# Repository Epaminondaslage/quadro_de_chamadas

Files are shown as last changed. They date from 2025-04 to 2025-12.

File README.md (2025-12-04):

<td style="width: 10%;">
    
</td>

## **CENTRO FEDERAL DE EDUCAÇÃO TECNOLÓGICA DE MINAS GERAIS**  
## **Departamento de Engenharia Elétrica - CEFET-MG**  
## **Coordenação do Curso de Eletrotécnica**  

###  Disciplina: **PLIEP - Prática de Laboratório de Instalações Eletricas Prediais**
## Guia de Aula – Quadro Sinalizador de Chamadas de Enfermagem

##  O que é um sistema de chamada de enfermagem?

É um sistema que permite aos pacientes sinalizar a necessidade de assistência por parte da equipe de enfermagem, geralmente em ambientes hospitalares ou casas de repouso. Ele utiliza sinais sonoros e luminosos para alertar os profissionais de saúde sobre a necessidade de atendimento. 

Esse sinal é enviado para uma **central de monitoramento** 🛋️, localizada em local visível a todos os profissionais. Veja na imagem que segue um modelo comercial empregado em hospitais e clinicas.

<p align="center">
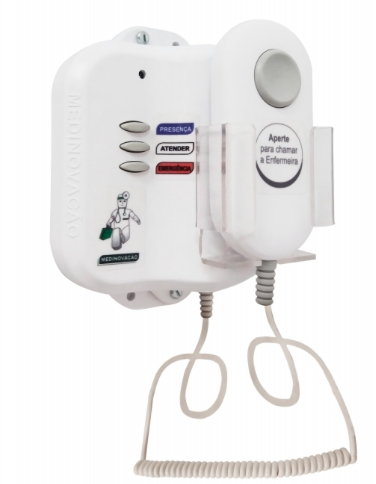
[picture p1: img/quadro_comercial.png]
Quadro de chamadas comercial
  
</p>

Além disso, o sistema permite que os profissionais de saúde **registrem a sua presença no leito** do paciente que gerou a chamada, sinalizando ao restante da equipe que o **atendimento está em andamento**.

## 🔧 Como funciona um sistema de chamada de enfermagem?

O paciente aciona a estação de chamada. 

O sinaleiro de porta acende, sinalizando a chamada externamente. 
A central do posto de enfermagem é acionada, indicando o número do leito ou do banheiro que solicitou ajuda. 
O profissional de enfermagem aciona o botão de presença para indicar que está atendendo à chamada. 
Após o atendimento, o profissional aciona novamente o botão de presença para desligar a chamada. 

<p align="center">
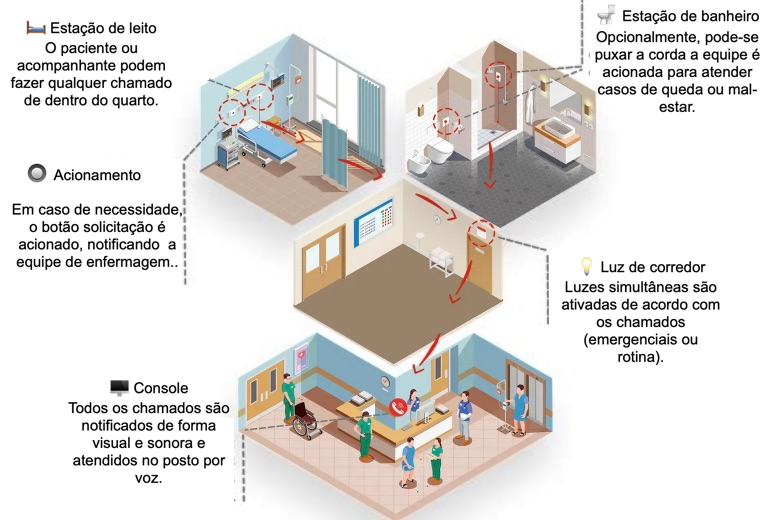
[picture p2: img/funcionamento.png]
Qoperacao
  
</p>

Benefícios:

    Melhora a comunicação entre pacientes e equipe de enfermagem. 

Agiliza o atendimento, reduzindo o tempo de espera dos pacientes. 
Aumenta a segurança dos pacientes, permitindo que eles solicitem ajuda rapidamente em caso de necessidade. 
Permite que a equipe de enfermagem monitore a atividade e a demanda de atendimento em tempo real. 

Um **sistema de chamada de enfermagem** é composto por diferentes dispositivos, adaptados às necessidades do ambiente hospitalar:

### 🛉 Estação de Chamada de Enfermagem

Dispositivos fixados na parede ou painéis de gases medicinais, acessíveis por um **cordão com pera sensível ao toque 🌟**.

### 🔦 Sinaleiro de Porta

Indicadores visuais fixados **acima das portas** para alertar sobre chamadas em andamento, utilizando diferentes **cores 🟥**.

### 🛋️ Central do Posto de Enfermagem

Dispositivo centralizado que **monitora e sinaliza** todas as chamadas ativas.

---

## Guia de Aula Prática: Montagem do Quadro de Chamadas

Com o objetivo de **capacitar os alunos do 2º ano do Curso de Eletrotécnica**, esta aula prática propõe a montagem de um **Quadro de Chamadas de Enfermagem**, que será instalado na parede externa do **Box 4** do Laboratório de Instalações Prediais.

Durante a atividade, os alunos aplicarão conceitos de eletrônica, comandos elétricos e automação, utilizando botões tipo pera, arandelas de sinalização e um sistema de controle baseado em microcontrolador **ESP32** com interface web.

➡️ Para detalhes completos do procedimento e materiais necessários, acesse o [Guia de Aula Prática de Montagem](https://github.com/Epaminondaslage/quadro_de_chamadas/blob/main/Guia_de_Aula_Pr%C3%A1tica.md).

---
## Retrofit do Quadro de Chamadas de Enfermagem

### O que é Retrofit?

**Retrofit** é o processo de **modernização e aprimoramento de sistemas, equipamentos ou estruturas já existentes**, visando **aumentar sua eficiência, funcionalidade e segurança**, ao mesmo tempo em que os adapta às **novas tecnologias**.  Em vez de substituir totalmente o que já foi construído, o retrofit promove uma **renovação inteligente**, aproveitando a infraestrutura física disponível e incorporando melhorias técnicas capazes de atender às exigências contemporâneas de desempenho e inovação.

➡️ Para detalhes completos do procedimento de retrofit veja : [Retrofit do Quadro de Chamadas de Enfermagem](https://github.com/Epaminondaslage/quadro_de_chamadas/blob/main/%F0%9F%94%A7%20Retrofit-do-Quadro-de-Chamadas.md).

---
## Projeto de um Quadro de Chamadas de Enfermagem Didático

O **Quadro de Chamadas** foi desenvolvido por professores do **CEFET-MG** com fins didáticos, com o objetivo de proporcionar aos alunos uma experiência prática em sistemas de automação e monitoramento. Utilizando o microcontrolador **ESP32**, o projeto simula um sistema real de chamadas de enfermagem, integrando entradas digitais (botões tipo pera) e saídas visuais (arandelas vermelhas) acionadas por relés. Além disso, inclui uma interface web para acompanhamento em tempo real das solicitações, reforçando conceitos de eletrônica, redes de comunicação e programação embarcada.

➡️ Para mais detalhes, consulte: [Projeto Quadro de Chamadas ESP32](https://github.com/Epaminondaslage/quadro_de_chamadas/blob/main/Projeto_Quadro_de_Chamadas_ESP32.md)

---

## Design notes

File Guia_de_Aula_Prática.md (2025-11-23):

<td style="width: 10%;">
    
</td>

## **CENTRO FEDERAL DE EDUCAÇÃO TECNOLÓGICA DE MINAS GERAIS**  
## **Departamento de Engenharia Elétrica - CEFET-MG**  
## **Coordenação do Curso de Eletrotécnica**  

## Disciplina: **PLIP - Prática de Laboratório de Instalações Prediais**
## Guia de Aula Prática: Montagem do Quadro de Chamadas de Enfermagem

## 🎓 Objetivo da Aula

Capacitar os alunos do **2º ano do Curso de Eletrotécnica** na montagem de um **Quadro de Chamadas de Enfermagem**, a ser instalado na parede externa do **Box 4** do Laboratório de Instalações Prediais.

## 📚 Descrição da Atividade

Cada box terá:
- Um **interruptor tipo pera** para acionar o chamado.

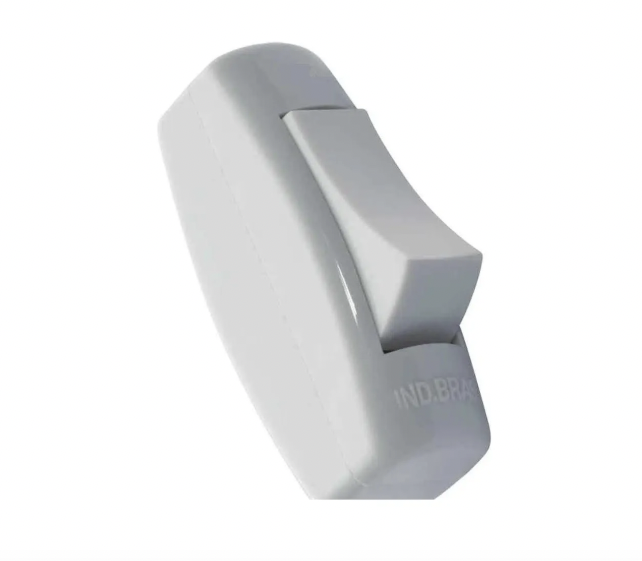
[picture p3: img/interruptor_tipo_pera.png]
interruptor_pera


- Uma **arandela vermelha** para sinalizar a solicitação de presença de um profissional de enfermagem.

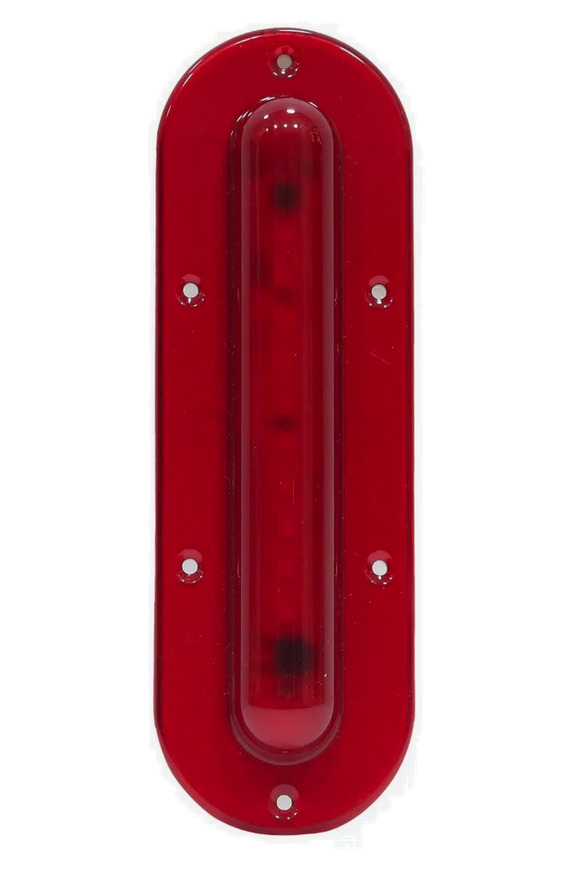
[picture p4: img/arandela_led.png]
arandela


O quadro central controlará as chamadas via **ESP32**, com registro e monitoramento através de uma **interface web**.

## 🛠️ Materiais Necessários

| Quantidade | Componente | Descrição |
|---|---|---|
| 1 | Quadro de Camada de Enfermagem | Microcontrolador e dispositivos eletronicos internos |
| 4 | Interruptor tipo pera | Acionadores de chamada |
| 4 | Arandelas vermelhas (127V)  | Indicadores de chamada |
| 1 | Fonte 127V  | Fonte de alimentação para o Quadro de chamadas |
| Cabos | Fios para conexões | Ligação dos dispositivos |

## 📊 Esquema de Conexão

- **Interruptores tipo pera** conectados às **entradas digitais** do Quadro onde está o ESP32.
- **Arandelas** conectadas a saídas dos **relés**, acionados pelas **saídas digitais** do ESP32.
- **Quadro de Chamadas de Enfermagem** alimentado em rede de 127V

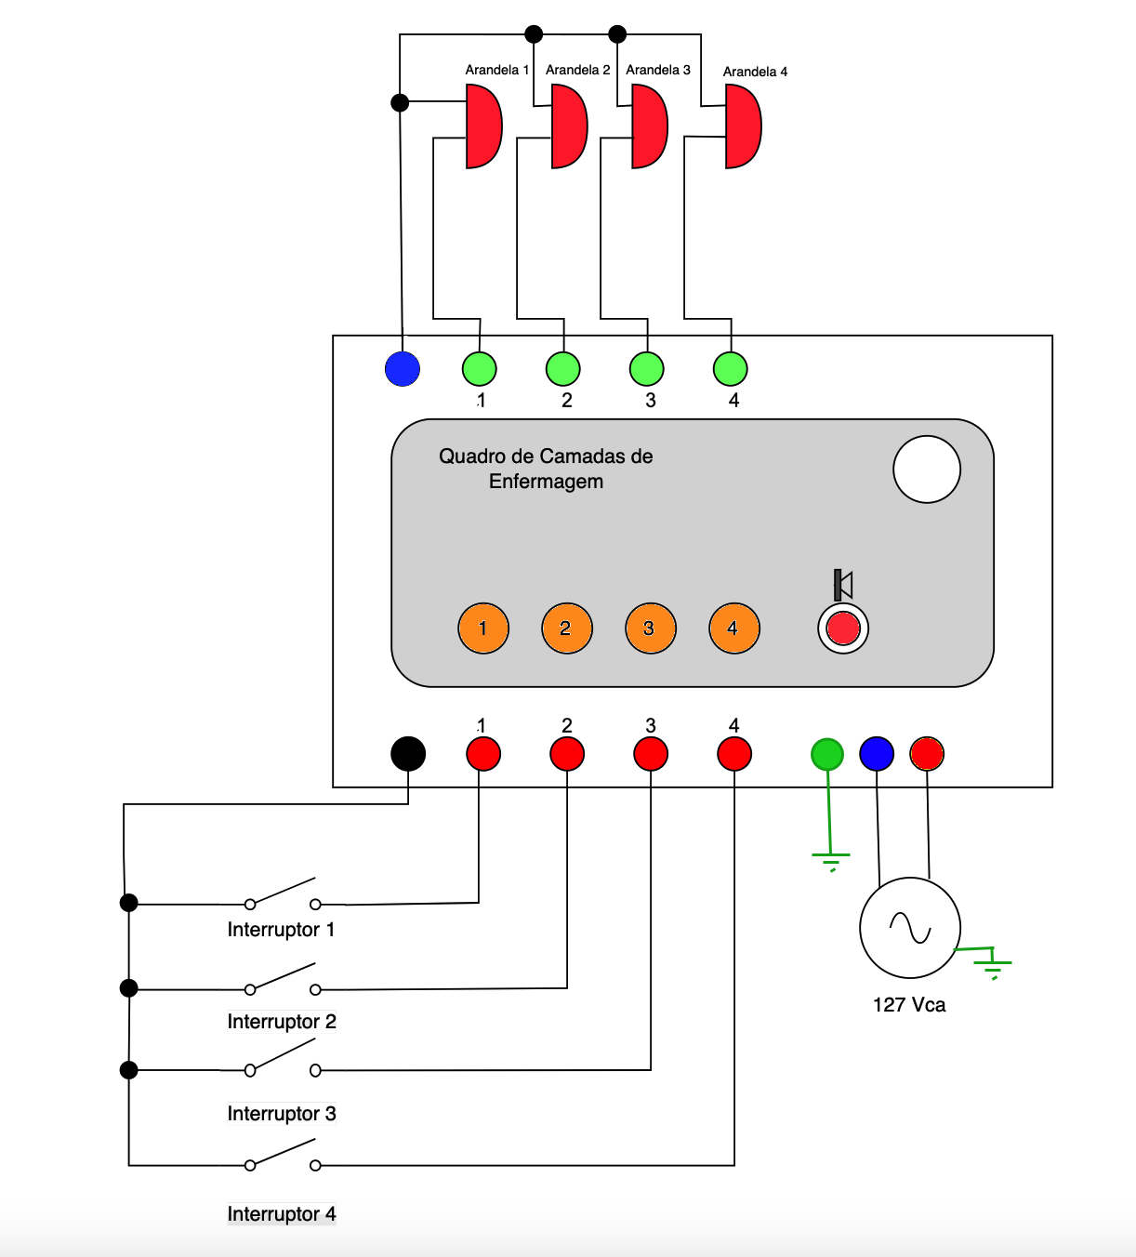
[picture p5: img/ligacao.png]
  

## 🔧 Procedimento de Montagem

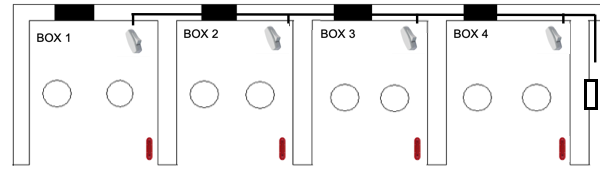
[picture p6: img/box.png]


## 📊 Atividades Propostas
- Realizar a montagem elétrica e mecânica dos equipamentos.
  
### 1. Ligação dos Interruptores
- Fixar o interruptor tipo pera em local acessível dentro de cada Box Didático
- Conectar uma extremidade do UTP e a outra a uma entrada no painel do ESP32 através do cabo UTP já instalado.

### 2. Ligação das Arandelas
- Instalar a arandela vermelha acima da porta dos Boxes 1 a 4.
- Conectar uma extremidade do cabo à arandela e a outra a uma entrada no painel do ESP32 através do cabo 1mm2 já instalado.

### 3. Instalação do Quadro de Chamadas
- Montar todo o circuito na base (painel) conectando os condutores conforme esquema que segue.

### 4. Testes Finais
- Acionar cada interruptor e verificar se a respectiva arandela acende.
- Acessar o wifi do Laboratório e monitorar o funcionamento do sistema pelo navegador de seu celular.Testar os comandos da interface web para monitorar os estados.

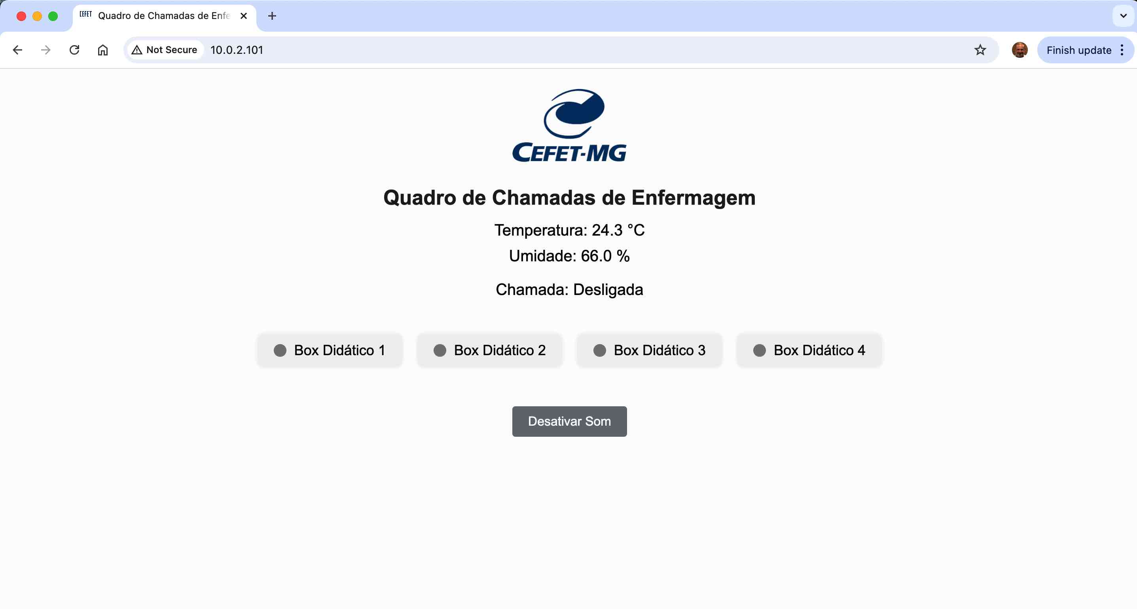
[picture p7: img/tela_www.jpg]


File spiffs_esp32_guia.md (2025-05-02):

# Guia: Usando `SPIFFS.h` no ESP32 

# 📦 O que é `SPIFFS.h`?

A biblioteca `SPIFFS.h` permite utilizar a memória **flash interna do ESP32** como um **sistema de arquivos**, possibilitando **armazenar e servir arquivos como HTML, CSS, JavaScript e imagens diretamente da placa**.

---

### ✅ Significado

**SPIFFS** = *SPI Flash File System*  
Sistema de arquivos leve, ideal para microcontroladores com memória flash limitada.

---

## ✅ Para que serve?

Com `SPIFFS`, é possível:

- Criar páginas web embarcadas (HTML/CSS/JS)
- Salvar imagens, logos ou ícones
- Armazenar configurações e logs
- Evitar hardcoding de textos HTML no `.ino`

---

## ✅ Exemplo de uso no código

```cpp
#include "SPIFFS.h"

void setup() {
  SPIFFS.begin(true); // Monta o sistema de arquivos
  server.serveStatic("/", SPIFFS, "/").setDefaultFile("index.html");
}
```

---

# 📦 Instalar Python 3, mkspiffs e enviar SPIFFS para ESP32 com MSYS2 (Arduino IDE 2.x)

Guia para instalar **Python 3**, `esptool.py`, `mkspiffs` e configurar o **MSYS2 MinGW 64-bit** para trabalhar com o ESP32.

---

## ✅ Etapa 1: Instalar Python 3 e pip

### ✅ 1. Baixar Python 3

[Baixe aqui](https://www.python.org/downloads/)

Marque **"Add Python 3.x to PATH"** na instalação.

### ✅ 2. Verificar instalação

```bash
python --version
pip --version
```

### ✅ 3. Instalar `esptool.py`

```bash
pip install esptool
esptool.py --help
```

---

## ✅ Etapa 2: Instalar o MSYS2

### ✅ 1. Baixar MSYS2

[Baixar aqui](https://www.msys2.org)

Instale em `C:\msys64`.

### ✅ 2. Abrir terminal correto

```
MSYS2 MinGW 64-bit
```

### ✅ 3. Atualizar sistema

```bash
pacman -Syu
```

### ✅ 4. Instalar ferramentas de compilação

```bash
pacman -S mingw-w64-x86_64-toolchain python-pip
```

---

## ✅ Etapa 3: Baixar o mkspiffs

[Download oficial do mkspiffs](https://github.com/earlephilhower/mkspiffs/releases)

Extraia para:

```
C:\esp32tools\mkspiffs.exe
```

---

## ✅ Etapa 4: Preparar o projeto

Estrutura recomendada:

```
meu_projeto/
├── meu_projeto.ino
└── data/
    ├── index.html
    ├── style.css
    └── script.js
```

---

## ✅ Etapa 5: Gerar a imagem SPIFFS

No terminal MSYS2 MinGW 64-bit:

```bash
cd /c/Users/SeuUsuario/Documents/Arduino/meu_projeto
/c/esp32tools/mkspiffs.exe -c data -b 4096 -p 256 -s 0x150000 spiffs.bin
```

---

## ✅ Etapa 6: Enviar a imagem para o ESP32

Identifique a porta COM do seu ESP32 e execute:

```bash
esptool.py --chip esp32 --port COM5 --baud 460800 write_flash 0x290000 spiffs.bin
```

---

## ✅ Endereço da partição SPIFFS

| Esquema de Particionamento | Endereço |
|---|---|
| Default 4MB with spiffs (1.2MB app) | 0x290000 |
| No OTA (2MB APP/2MB SPIFFS) | 0x290000 |

Verifique em:

> Arduino IDE > Ferramentas > Partition Scheme

---

## ✅ Etapa 7: Servir os arquivos SPIFFS

```cpp
#include "SPIFFS.h"

void setup() {
  SPIFFS.begin(true);
  server.serveStatic("/", SPIFFS, "/").setDefaultFile("index.html");
}
```

---

## ✅ Etapa 8: Testar no navegador

Acesse o IP do ESP32 no navegador para testar.

---

## ✅ Ambiente pronto!

Sistema configurado para enviar SPIFFS ao ESP32 usando Python 3, mkspiffs e MSYS2 na Arduino IDE 2.x.

---

# 💾 Arquivo BAT para Compilar e Enviar para o ESP32

## ✅ Objetivo do arquivo `.bat`

Automatizar:

1. Geração da imagem SPIFFS (`spiffs.bin`)
2. Upload da imagem SPIFFS para o ESP32

## ✅ Comandos usados:

### 1. Geração do spiffs.bin

```bash
mkspiffs.exe -c quadro_de_chamadas\quadro_de_chamadas\data -b 4096 -p 256 -s 0x150000 spiffs.bin
```

Parâmetros:
- `-c`: caminho dos arquivos
- `-b 4096`: tamanho do bloco
- `-p 256`: tamanho da página
- `-s 0x150000`: tamanho reservado para SPIFFS

### 2. Upload para ESP32

```bash
python -m esptool --chip esp32 --port COM8 --baud 460800 write_flash 0x290000 spiffs.bin
```

Parâmetros:
- `--chip esp32`: define o chip
- `--port COM8`: porta serial
- `--baud 460800`: velocidade de gravação
- `write_flash 0x290000`: endereço de gravação

---

## ✅ Resumo Simplificado

| Etapa | Ação |
|:-----|:-----|
| 1️⃣ | Gerar imagem SPIFFS |
| 2️⃣ | Gravar SPIFFS no ESP32 |

Ao executar o `.bat`, todo o processo é automático! 

---

## ✅ Arquivos e Ferramentas

| Arquivo/Ferramenta | Função |
|---|---|
| `mkspiffs.exe` | Gera imagem SPIFFS |
| `esptool.py` | Envia imagem para ESP32 |
| `spiffs.bin` | Imagem dos arquivos |
| `.bat` | Automatiza processo |

---

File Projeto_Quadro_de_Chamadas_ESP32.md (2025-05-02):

# Projeto: Quadro de Chamadas (ESP32- WROOM)

Este projeto desenvolve um painel de chamadas interativo baseado no microcontrolador ESP32 🔌, integrando funcionalidades de automação, conectividade e monitoramento em tempo real. O sistema permite a ativação de chamadas por meio de botões tipo pera e sinaliza a solicitação através de arandelas luminosas controladas por relés. Além disso, disponibiliza uma interface web moderna, acessível via Wi-Fi, para visualização do status das chamadas, monitoramento de temperatura e umidade, e controle do buzzer de alerta.
A estrutura modular e a programação flexível do ESP32 garantem escalabilidade, permitindo futuras expansões como notificações remotas e integração com redes de automação predial.

## ✅ Visão geral

Este projeto implementa um painel de monitoramento com ESP32 utilizando:

- Conexão Wi-Fi
- Sensor de temperatura e umidade DHT11
- Buzzer
- Quatro entradas digitais
- Quatro saídas digitais
- Interface web (HTML/CSS/JS via SPIFFS)
- Display de status com atualização dinâmica
- Desativação do buzzer por botão físico ou pela web

---
## 🌐 Funcionalidades

- 🔢 Exibição da temperatura e umidade em tempo real (acessível por Wi-Fi 📡)
- 🔹 Indicadores visuais de entrada (bolinhas cinza e verde 🔘)
- 💔 Botão para desativar o buzzer por 1 minuto
- 🌍 Logotipo do **CEFET-MG** exibido via SPIFFS
- 🔄 Atualizações automáticas da página usando AJAX
- 🖥️ Interface web responsiva hospedada no ESP32

---

## Porque o ESP32?

O ESP32 foi escolhido para o projeto do Quadro de Chamadas por oferecer conexão Wi-Fi integrada, múltiplos pinos de entrada e saída digitais, alto poder de processamento e ampla memória flash. Essas características permitem a criação de um sistema de monitoramento via navegador, com atualização em tempo real e possibilidade de armazenamento de páginas web (HTML, CSS, JS) diretamente na memória da placa, utilizando SPIFFS. Além disso, o ESP32 é compatível com a plataforma Arduino IDE, facilitando o aprendizado e a programação para alunos do curso técnico.

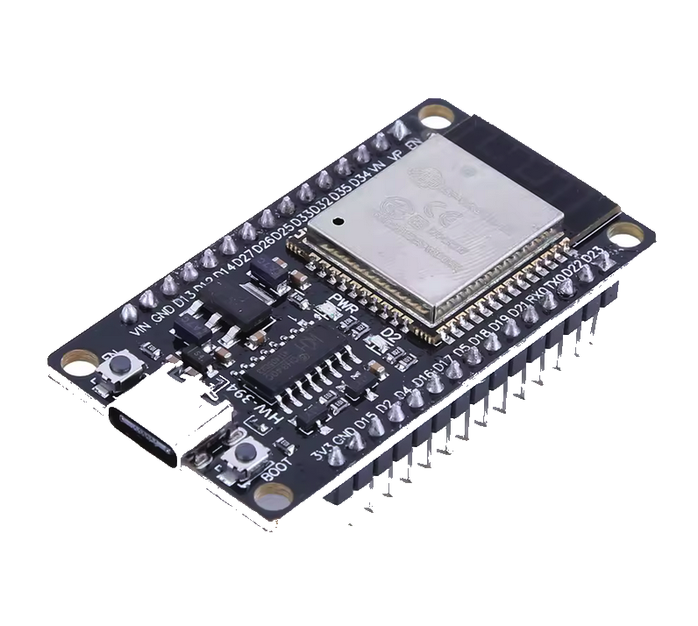
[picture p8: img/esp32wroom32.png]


Sua estrutura robusta, baixo custo e grande suporte da comunidade o tornam ideal para projetos educacionais que exigem confiabilidade e flexibilidade. A utilização do ESP32 possibilita ainda futuras expansões do sistema, como integração com controle remoto via MQTT, monitoramento por smartphones e atualizações OTA, preparando os alunos para tecnologias modernas de automação e conectividade.

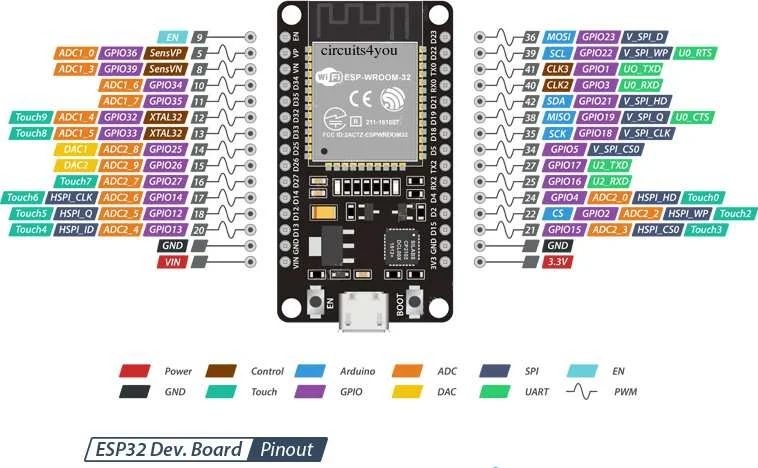
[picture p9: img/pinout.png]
Pinout ESP32


- 🔹 4 entradas digitais (botões de chamada)
- 🔹 4 saídas digitais (LEDs e relés para cargas em 127V)
- 🔹 Buzzer 🔊 com controle de desativação temporária (mute)
- 🌡️ Sensor de temperatura e umidade **DHT11**
- 🖥️ Interface web moderna, servida via **SPIFFS**

## 🔔 Modulo Relé 3.3V

O módulo relé 2 canais 3.3V é um dispositivo que permite controlar dois circuitos de corrente alternada (AC) ou contínua (DC) por meio de sinais de baixa tensão, sendo compatível com microcontroladores como o ESP32, ESP8266 e Raspberry Pi. Cada canal possui um relé eletromecânico com contatos NO (normalmente aberto), NC (normalmente fechado) e COM (comum), suportando até 10A em 250V AC ou 30V DC. O módulo é acionado por nível lógico baixo (LOW), conta com optoacopladores para isolamento elétrico entre a carga e o circuito de controle, e possui LEDs indicadores para sinalizar o estado de cada relé.

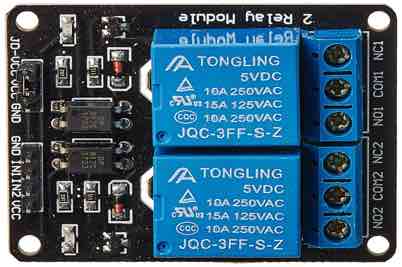
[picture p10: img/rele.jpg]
rele


---
## 🌡 Sensor DHT11

O DHT11 é um sensor digital de baixo custo usado para medir temperatura e umidade relativa do ar. Ele é amplamente utilizado em projetos educacionais, hobby e sistemas de automação residencial devido à sua simplicidade de uso e integração fácil com microcontroladores como Arduino, ESP32 e ESP8266.

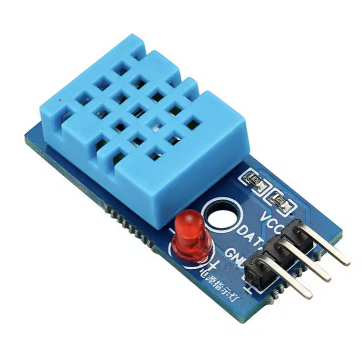
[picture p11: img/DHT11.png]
dht11


- Ligado ao GPIO 15
- Mostra temperatura e umidade no display e na interface web
- Se não estiver conectado: mostra `Ind`

---

## 🔔 Controle de Buzzer

O Buzzer é um dispositivo eletrônico utilizado para gerar sinais sonoros. Ele é muito comum em projetos de automação, sistemas de alarme, interfaces de usuário e aplicações educacionais. Existem duas versões principais: o buzzer ativo e o buzzer passivo, cada um com características específicas.

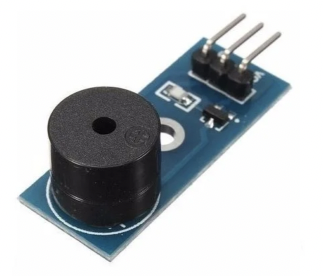
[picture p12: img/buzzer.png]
buzzer


- Ativado por qualquer uma das 4 entradas digitais
- Desligado por:
  - Botão físico no GPIO 27
  - Botão na interface web
- Fica desativado por 60 segundos

---
 ## 📂 Diagrama de conexões do sistema

O projeto consiste em um sistema embarcado de sinalização e monitoramento baseado no microcontrolador ESP32, voltado para aplicações didáticas e automação predial. A arquitetura foi concebida para garantir confiabilidade, flexibilidade e baixo custo, utilizando recursos nativos do ESP32, como conectividade Wi-Fi e suporte a sistemas de arquivos SPIFFS, permitindo a disponibilização de uma interface web responsiva acessível via navegador. O sistema conta com 4 entradas digitais para acionamento por botões físicos e 4 saídas digitais destinadas ao controle de cargas ou sinalização visual por LEDs e relés, operando inclusive em tensões de 127V~. Inclui ainda um buzzer piezoelétrico com controle de silenciamento temporário e um sensor DHT11, responsável pela leitura de temperatura e umidade relativa.

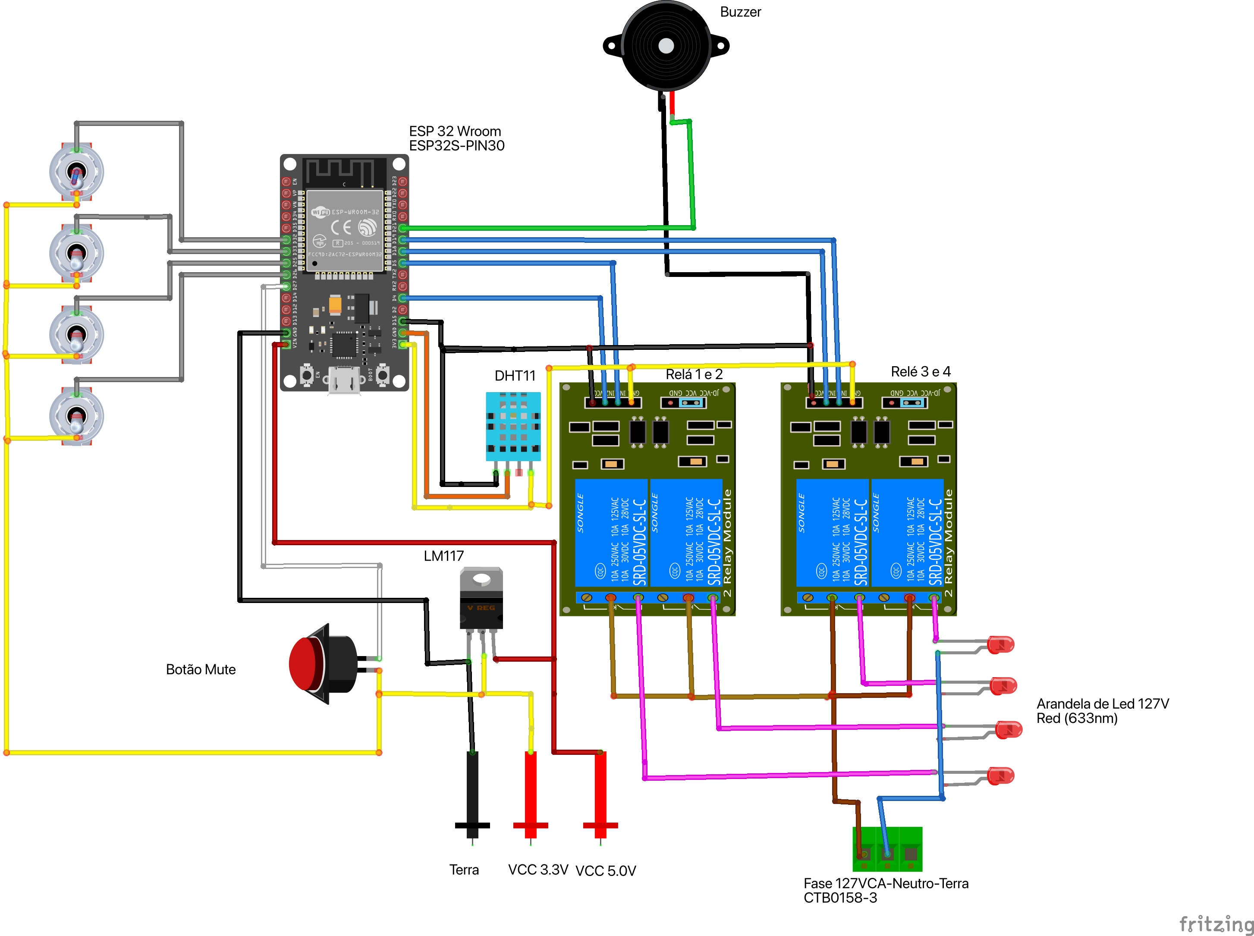
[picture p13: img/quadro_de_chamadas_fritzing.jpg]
quadro de chamadas fritzing


Veja a definição dos pinos no .INO:

```
#define DHTPIN 15
#define DHTTYPE DHT11
DHT dht(DHTPIN, DHTTYPE);
WebServer server(80);
const int entradas[4] = {32, 33, 25, 26};
const int saidas[4] = {4, 5, 18, 19};
const int buzzerPin = 21;
const int botaoMute = 27;
```

### 📌 Pinos utilizados na parte superior da placa  (com USB à esquerda)

| Ordem na placa | Nome na placa  | GPIO | Sua utilização |
|---|---|---|---|
| 1 | VIN | 5V | Alimentação In |
| 2 | GND | GND | Terra comum |
| 6 | D27 | GPIO27 | **Botão Mute** |
| 7 | D26 | GPIO26 | **Entrada 4** |
| 8 | D25 | GPIO25 | **Entrada 3** |
| 9 | D33 | GPIO33 | **Entrada 2** |
| 10 | D32 | GPIO32 | **Entrada 1** |

---

### 📌 Pinos usados na parte inferior da Placa (com USB à esquerda)

| Ordem na placa | Nome na placa | GPIO real | Sua utilização |
|---|---|---|---|
| 1 | 3.3 | 3.3 | Alimentação Saída |
| 2 | GND | GND | Terra comum |
| 3 | D15 | GPIO15 | **DHT11** |
| 5 | D04 | GPIO04 | **Saída 1** |
| 8 | D05 | GPIO05 | **Saída 2** |
| 9 | D18 | GPIO18 | **Saída 3** |
| 10 | D19 | GPIO19 | **Saída 4** |
| 11 | D21 | GPIO21 | **Buzzer** |

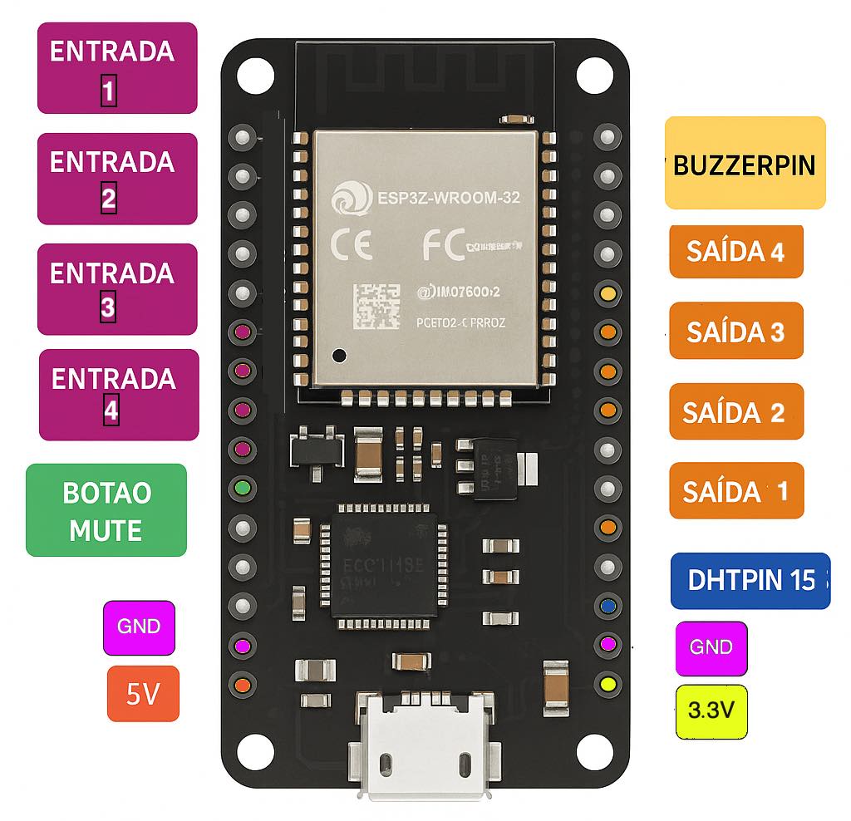
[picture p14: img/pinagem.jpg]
Pinagemr


---

 ## 📂 Códigos de programação e Estrutura de Software do ESP32 WROOM

Todos os programas desenvolvidos encontram-se disponibilizados neste repositório, na pasta **Quadro_de_chamadas**, e podem ser livremente acessados e utilizados como referência para o desenvolvimento de outras aplicações.

```
quadro_de_chamadas/
├── quadro_de_chamadas.ino
└── data/
    ├── index.html
    ├── style.css
    ├── script.js
    └── logo.png
```
---

## 🔧 Como Usar os códigos

1. Abra `quadro_de_chamadas.ino` na IDE do Arduino.
2. Instale as bibliotecas necessárias:
   - `WiFi` 📡
   - `WebServer` 🔹
   - `DHT sensor library` 🌡️
3. Faça upload do código para o ESP32.
4. Envie os arquivos da pasta `data/` para o SPIFFS. Veja o tutorial: [Guia de uso do SPIFFS no ESP32](https://github.com/Epaminondaslage/quadro_de_chamadas/blob/main/spiffs_esp32_guia.md) para mais detalhes sobre o sistema de arquivos SPIFFS e como fazer upload no ˜ESP32.
5. Acesse o IP do ESP32 no navegador 🔍.

## 📡 EComunicação entre o sensor o ESP32 e a Pagina HTML:  JSON

O  **JSON** é apenas **texto estruturado** em pares **chave: valor**. O navegador entende e usa facilmente essas informações.

## 🧐 Visão Geral

- O **ESP32** (programa `.ino`) gera um **JSON** com os dados.
- A **página HTML** faz uma **requisição HTTP** para buscar o JSON.
- O **ESP32 responde** com o JSON.
- O **JavaScript da página** interpreta o JSON e **atualiza a interface**.

---

### 1. No ESP32 (.ino)

```cpp
void handleStatus() {
  String json = "{";
  json += "\"temperatura\":24.5,";
  json += "\"umidade\":60.0,";
  json += "\"entrada1\":true,";
  json += "\"entrada2\":false";
  json += "}";
  server.send(200, "application/json", json);
}
```

- O ESP32 cria uma **resposta JSON** e envia para quem acessar `/status.json`.

### 2. No HTML + JavaScript

```html
<script>
function atualizarDados() {
  fetch('/status.json')
    .then(response => response.json())
    .then(data => {
      console.log(data); // Exibe o JSON no console
      document.getElementById('temp').innerText = data.temperatura + ' °C';
      document.getElementById('umid').innerText = data.umidade + ' %';
    })
    .catch(error => console.error('Erro:', error));
}

// Atualiza a cada 5 segundos
setInterval(atualizarDados, 5000);
</script>

<p>Temperatura: <span id="temp">--</span></p>
<p>Umidade: <span id="umid">--</span></p>
```

- `fetch('/status.json')` pede o JSON.
- O JavaScript atualiza o HTML com os dados recebidos.

---

## 💾 Exemplo de JSON recebido

```json

{
  "temperatura": 24.5,
  "umidade": 60.0,
  "buzzer": false,
  "entrada1": true,
  "entrada2": false,
  "entrada3": true,
  "entrada4": false
}
```

---

## 📝 Resumo do Fluxo

ESP32 gera JSON -> HTML pede JSON -> ESP32 responde -> HTML atualiza tela

| No ESP32 (.ino) | Na Página HTML/JS |
|:---|:---|
| Monta e envia o JSON | Faz `fetch` e consome o JSON |
| Usa `server.send(...)` | Usa `fetch('/status.json')` |
| Dados gerados | Dados exibidos |

---

 ## 🔍 Monitor Serial

Após iniciar o ESP32, o monitor serial , conectado a portrta usb do ESP32 e a interface do IDE do arduino pode monitorar e  deve exibir:

```
WiFi conectado
IP atribuído: 240.0.0.x
✅ SPIFFS montado com sucesso
Arquivos SPIFFS disponíveis:
  /index.html
  /style.css
  /script.js
  /logo.png
```
---
## 📡 Conexão Wi-Fi

A integração com redes sem fio permite a expansão natural do sistema para aplicações de Internet das Coisas (IoT), com publicação de eventos em tempo real por meio do protocolo MQTT, possibilitando o envio de dados para servidores locais ou em nuvem. Essa funcionalidade viabiliza o monitoramento remoto por dashboards web ou aplicações móveis, além de facilitar a integração com sistemas supervisórios ou plataformas de automação predial. A estrutura modular e o uso de tecnologias abertas tornam o projeto ideal para o ensino técnico de sistemas embarcados, protocolo de comunicação, lógica de controle e aplicações conectadas.

Para acessar a interface web do Quadro de Chamadas, é necessário primeiro se conectar à rede Wi-Fi do Laboratório de Instalações Prediais utilizando as seguintes credenciais:

```cpp
SSID "DEE-Prediais"
PASSWORD "prediais123"
```
Cada celular ou tablet irá obter um endereço IP dinâmico conforme este exemplo abaixo.

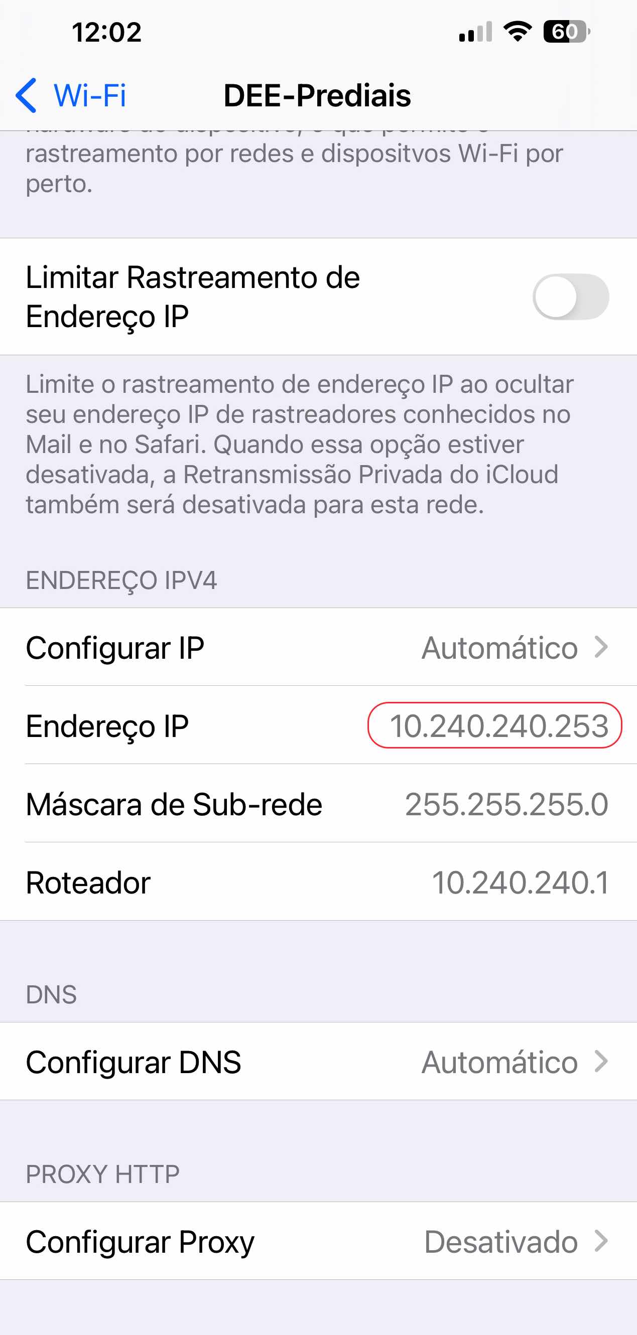
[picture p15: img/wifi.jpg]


Após a conexão, basta abrir o navegador em seu dispositivo (computador, tablet ou smartphone) e digitar o IP do ESP32 para acessar o painel de chamadas, visualizar o status das entradas e saídas e monitorar as informações de temperatura e umidade em tempo real.

---
## 🌐 Acesso à interface

Devera procurar o IP do ESP alocado pelo DHCP do roretador do laboratório de Instalações Prediais. A interface carregará os dados em tempo real.
Abra no navegador:

```
http://10.240.240.x
```

box

---

## 💾 O que é SPIFFS?

**SPIFFS.h** é a biblioteca utilizada no ESP32  para armazenar e gerenciar arquivos na memória flash da placa, como um mini "pendrive" interno 📥.

> **SPIFFS** = *SPI Flash File System*

É um sistema de arquivos leve e eficiente, ideal para microcontroladores.

> 📘 **Referência:**  
> Consulte o [Guia de uso do SPIFFS no ESP32](https://github.com/Epaminondaslage/quadro_de_chamadas/blob/main/spiffs_esp32_guia.md) para mais detalhes sobre o sistema de arquivos SPIFFS.

---

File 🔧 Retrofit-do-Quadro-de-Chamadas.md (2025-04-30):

# 🔧 Retrofit do Quadro de Chamadas de Enfermagem Eletrônico

## 🔬 O que é Retrofit?

**Retrofit** é o processo de **modernização ou atualização de sistemas, equipamentos ou estruturas existentes**, com o objetivo de aumentar sua eficiência, funcionalidade, segurança e adaptá-los a novas tecnologias, sem a necessidade de substituição completa. É uma **renovação inteligente**: aproveita-se a infraestrutura física existente, mas introduzem-se melhorias técnicas para atender às demandas atuais.

No Laboratório de Instalações Prediais do CEFET-MG temos dois modelos de quadro de chamadas de enfermeiros. 

### 1- Quadro Eletromecânico

Um quadro de chamadas de enfermagem eletromecânico é um sistema simples utilizado em hospitais para indicar que um paciente solicitou ajuda. Cada leito possui um botão que, ao ser pressionado, acende uma luz  e  acionar uma campainha no painel central. O painel, instalado na enfermaria, possui lâmpadas correspondentes a cada leito, e o alarme permanece ativo até ser desligado manualmente.

Esse sistema utiliza componentes como relés, lâmpadas sinalizadoras e fiação dedicada. Apesar de ser robusto, não permite registro digital, priorização de chamados ou visualização remota, tornando-se limitado.
<p align="center">
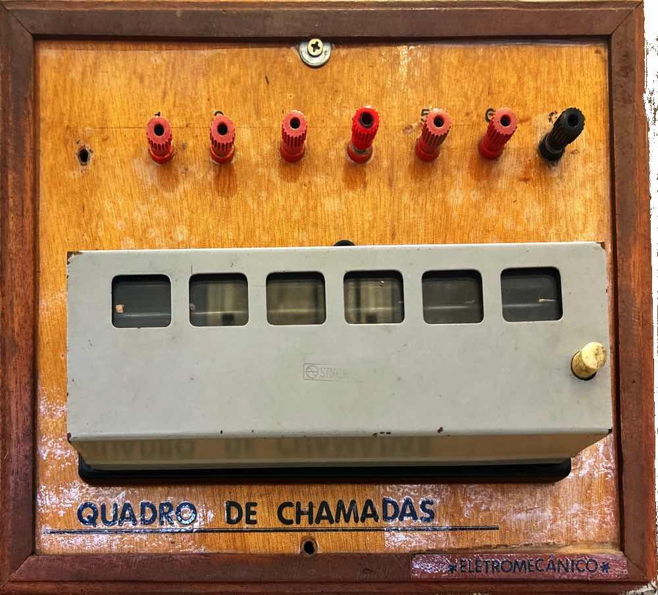
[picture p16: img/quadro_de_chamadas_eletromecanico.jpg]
Painel Eletromecanico
  
</p>

### 2- Quadro Eletrônico

Um quadro de chamadas de enfermagem eletrônico é um sistema, mais moderno que o eletromecânico, utilizado para indicar que um paciente solicitou atendimento. Cada leito possui um botão de chamada que, ao ser pressionado, envia um sinal elétrico de 12V em corrente contínua (CC), alimentando um LED indicador correspondente no painel central.

O painel, normalmente instalado na enfermaria, contém LEDs sinalizadores para cada leito e uma cigarra sonora (campainha), que é acionada por meio de um relé. O sistema permanece ativo — com o LED aceso e a cigarra tocando — até que o chamado seja cancelado manualmente, geralmente por um botão localizado no leito.

<p align="center">
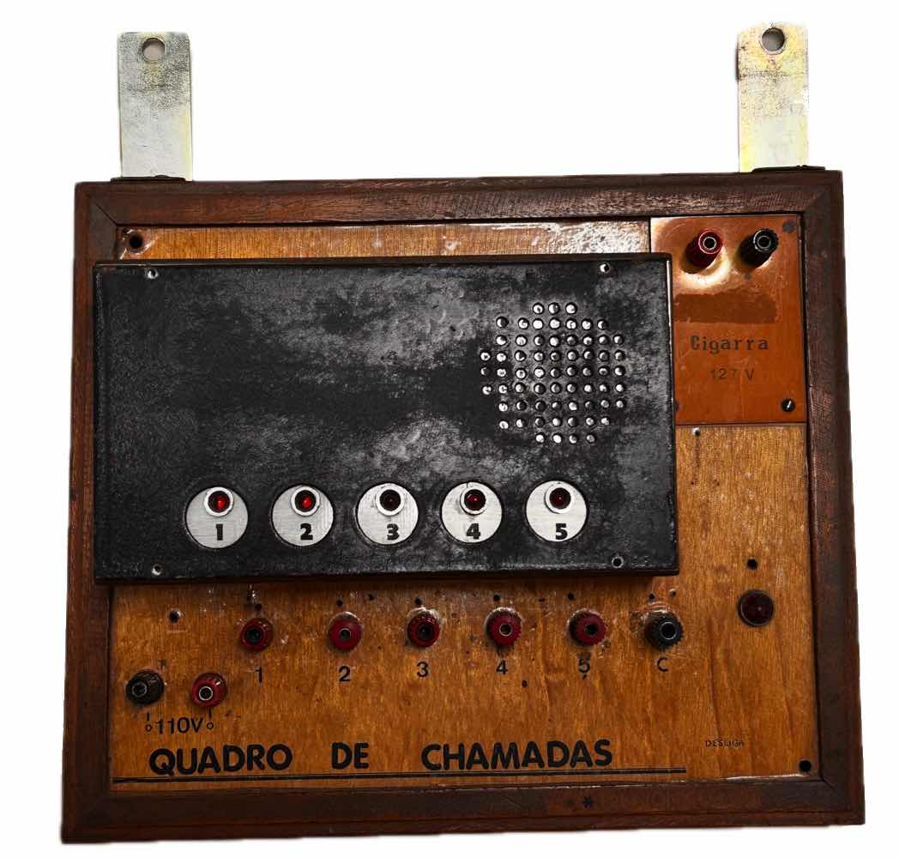
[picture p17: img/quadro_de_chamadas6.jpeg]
Painel atual
  
</p>

A implementação do retrofit no Quadro de Chamadas de Enfermagem Eletrônico proporciona aos alunos do curso de Eletrotécnica uma experiência prática com tecnologias atuais, promovendo o desenvolvimento de competências em instalações elétricas, automação e Internet das Coisas (IoT).

## 🔧 Aplicação de Retrofit no Quadro de Chamadas de Enfermagem Eletrônico

# 🛠️ Etapas do Retrofit

1. **Avaliação**  
   Inspecionar o sistema existente e identificar falhas e necessidades de atualização.

2. **Definição de Objetivos**  
   Estabelecer metas como modernização, aumento de eficiência ou adequação a normas.

3. **Projeto e Planejamento**  
   Elaborar o novo projeto técnico, selecionar materiais e definir cronograma e orçamento.

4. **Preparação**  
   Desligar e proteger sistemas existentes, remover componentes obsoletos.

5. **Execução**  
   Instalar novos equipamentos e integrar tecnologias modernas.

6. **Testes e Comissionamento**  
   Validar o funcionamento dos novos sistemas e fazer ajustes.

7. **Documentação e Treinamento**  
   Atualizar documentos e treinar os usuários.

8. **Monitoramento Inicial**  
   Acompanhar o desempenho e corrigir eventuais falhas.

No caso do **Quadro de Chamadas de Enfermagem Eletrônico**, o retrofit consistiu em:

- Substituição dos interruptores por tipo  Pera.
- Substituição das arandelas por **Sinalizadores de LEDs** de alta luminosidade**.
- Substituição da campahinha por um sinal audivel eletrônico que pode ser mutado.
- Controle dos chamados utilizando um **microcontrolador ESP32**.
- Atualização do sistema de alimentação para **baixa tensão**, aumentando a segurança e evitando riscos de curtos-circuitos.
- Separacão dos circuitos de controle (ESP32) e de iluminação (LEDs), garantindo maior proteção e robustez.
<table>
  <tr>
    <td align="center">
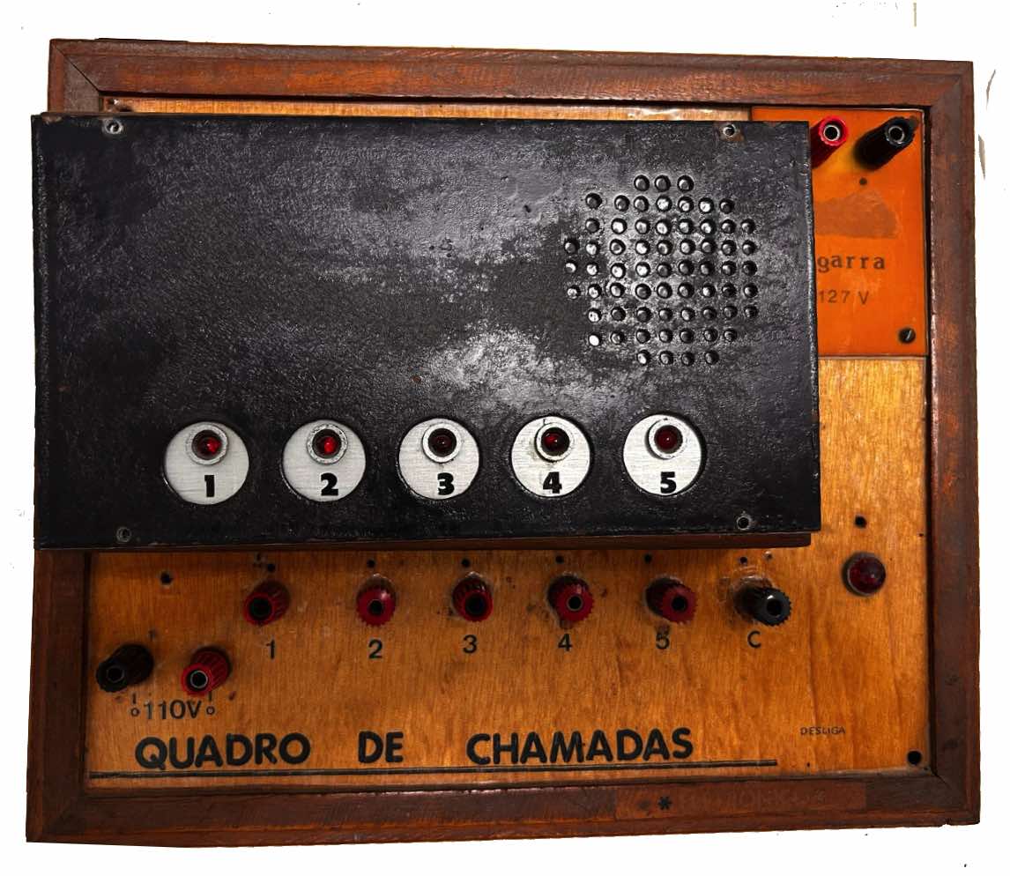
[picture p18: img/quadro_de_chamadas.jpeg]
Detalhe 1
      
    </td>
    <td align="center">
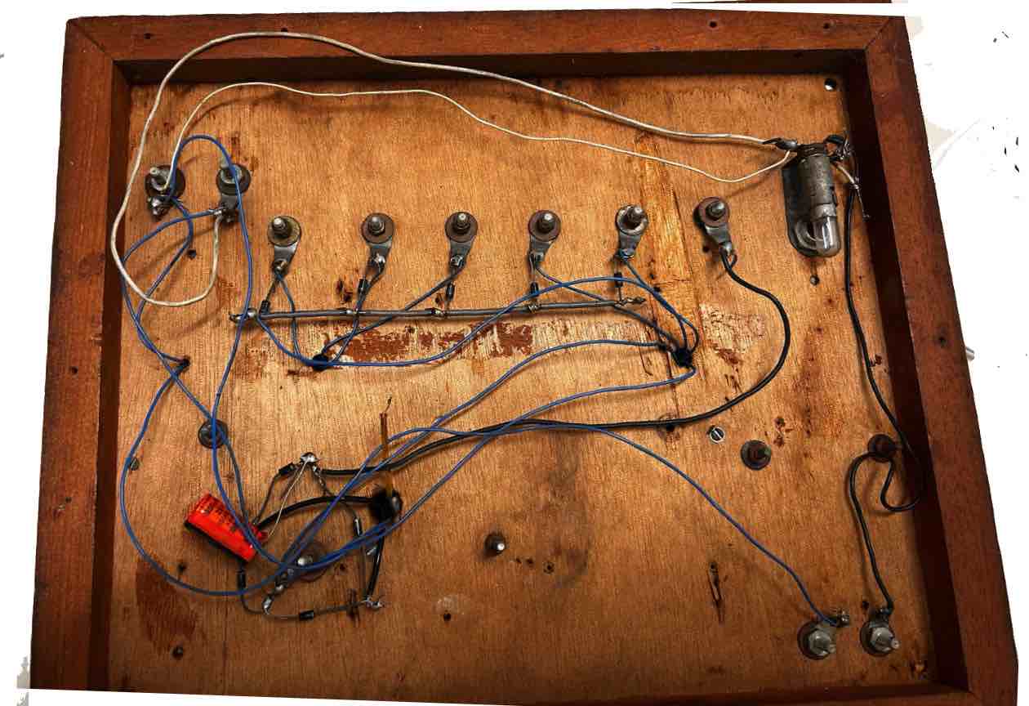
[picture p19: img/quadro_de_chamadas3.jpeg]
Detalhe 2
      
    </td>
    <td align="center">
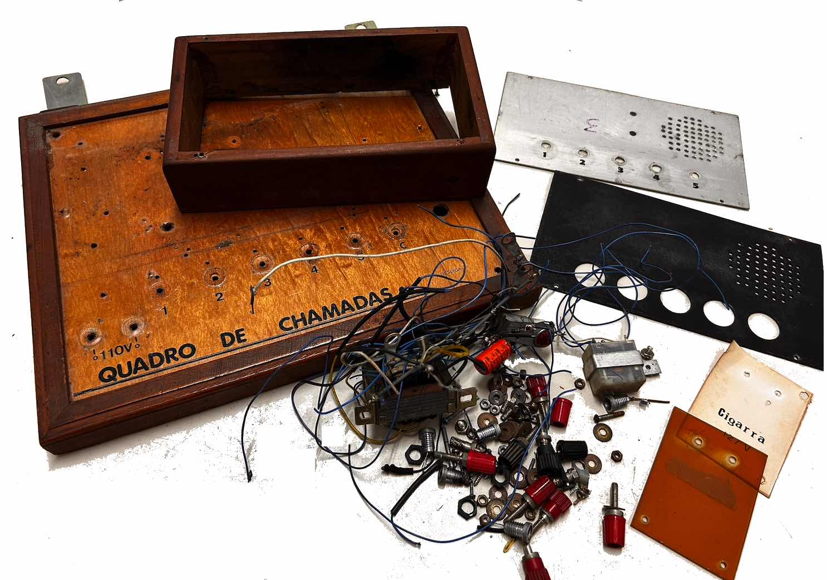
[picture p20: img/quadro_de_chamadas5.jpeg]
Detalhe 3
      
    </td>
  </tr>
</table>
  <table>
  <tr>
    <td align="center">
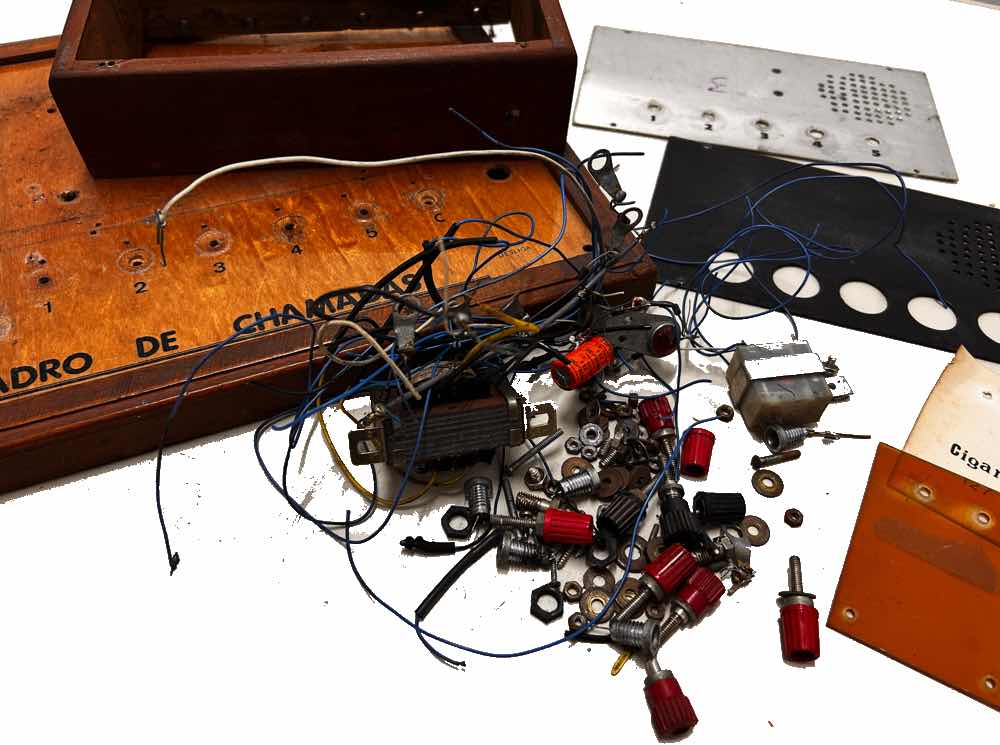
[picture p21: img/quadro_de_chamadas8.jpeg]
quadro_de_chamadas
      
    </td>
    <td align="center">
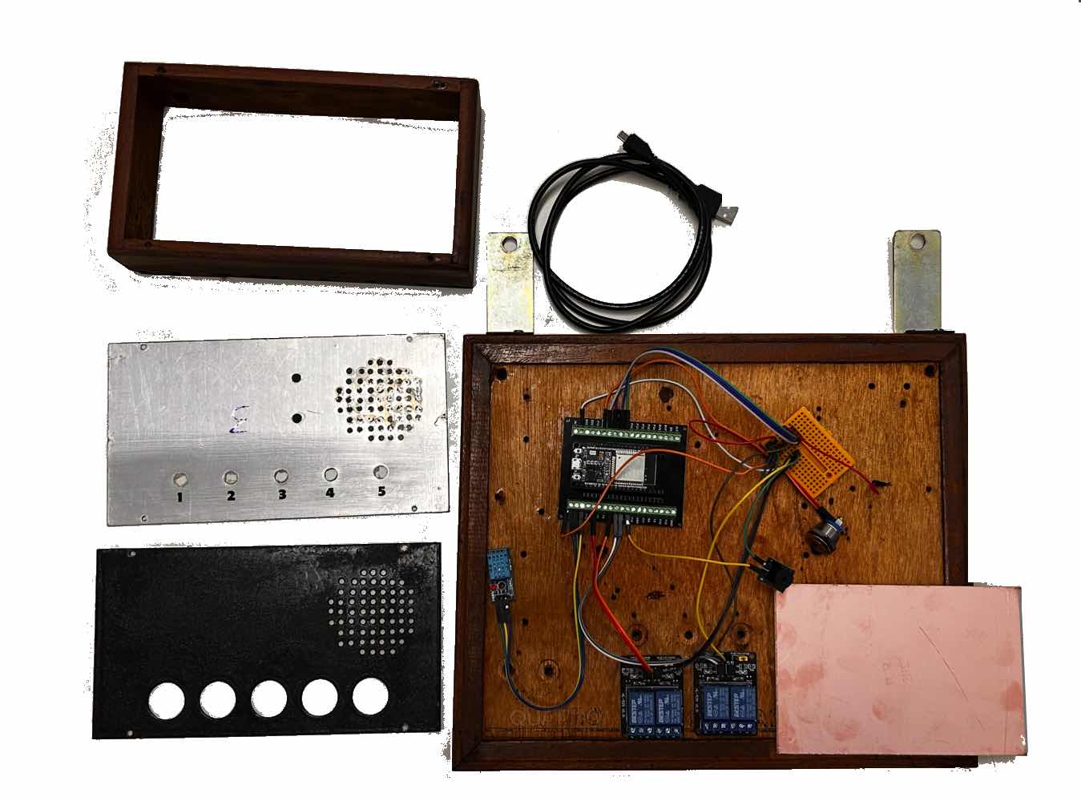
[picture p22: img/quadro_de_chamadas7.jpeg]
quadro_de_chamadas
      
    </td>
    <td align="center">
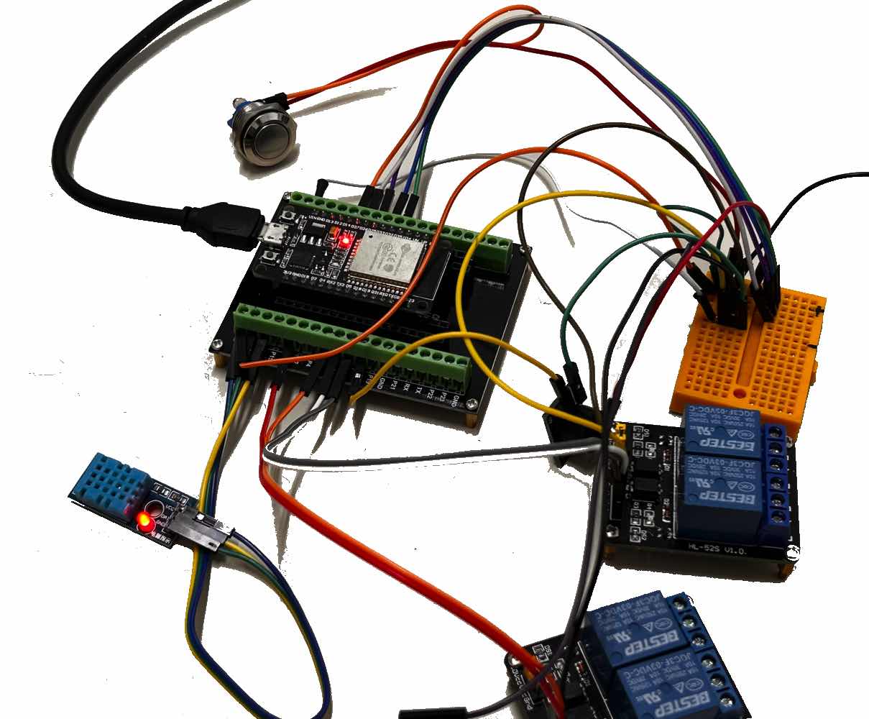
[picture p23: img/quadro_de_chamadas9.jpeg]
quadro_de_chamadas
      
    </td>
  </tr>
</table>
  <table>
  <tr>
    <td align="center">
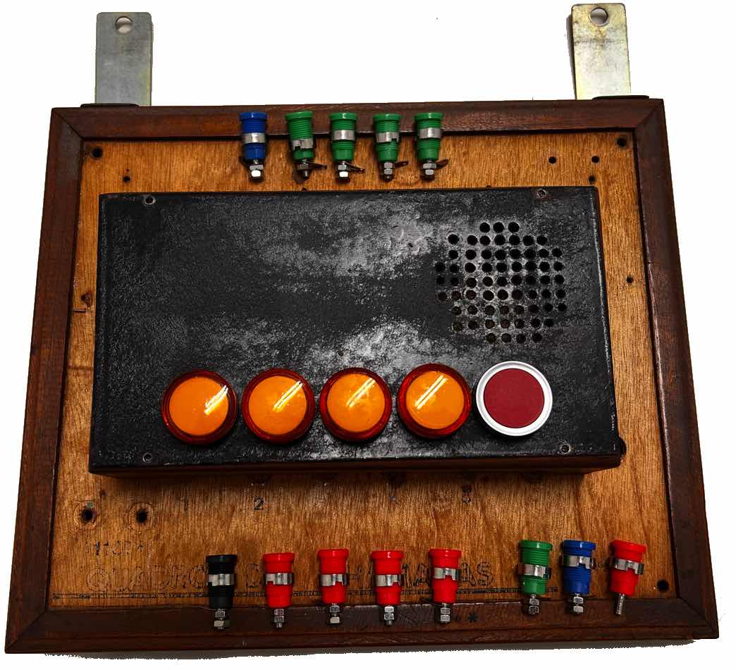
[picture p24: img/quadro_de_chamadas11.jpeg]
quadro_de_chamadas
      
    </td>
    <td align="center">
      quadro_de_chamadas
    </td>
    <td align="center">
      quadro_de_chamadas
    </td>
  </tr>
</table>
---

## Benefícios da Modernização do Sistema

A modernização implementada no sistema proporcionou uma série de melhorias relevantes, descritas a seguir:

- **Redução significativa do consumo de energia**  
  A atualização de componentes e a otimização dos circuitos resultaram em um sistema mais eficiente energeticamente, reduzindo o custo operacional e o impacto ambiental.

- **Maior confiabilidade operacional**  
  A substituição de dispositivos obsoletos por equipamentos mais robustos e modernos diminuiu a ocorrência de falhas, aumentando a disponibilidade do sistema e a segurança das operações.

- **Introdução do monitoramento remoto via Wi-Fi**  
  O sistema passou a oferecer acesso remoto em tempo real por meio de uma interface web responsiva, permitindo acompanhamento e gestão das chamadas de forma prática, tanto em dispositivos móveis quanto em computadores.

- **Manutenção da função original de chamada visual**  
  A funcionalidade principal de chamada visual foi preservada, agora utilizando tecnologias mais seguras e duráveis, como LEDs de alta eficiência, garantindo melhor visibilidade e maior vida útil dos componentes.

- **Preparação para futuras expansões**  
  O projeto foi estruturado para permitir novas funcionalidades, como:
  - **Registro de eventos**: Armazenamento de dados de acionamentos para análise e auditoria.
  - **Envio de notificações automáticas**: Alertas enviados por e-mail, SMS ou aplicativos em caso de eventos críticos.
  - **Integração com sistemas de automação predial**: Comunicação com plataformas de automação para controle centralizado de múltiplos sistemas (iluminação, climatização, segurança, etc.).
  - **Implementação de recursos IoT (Internet das Coisas)**:  
    Inclusão de sensores e atuadores inteligentes, com possibilidade de expansão modular e monitoramento integrado à nuvem.
  - **Gravação dos eventos em broker MQTT**:  
    Cada chamada ou evento é registrado em tempo real via protocolo MQTT, permitindo armazenamento seguro, integração com dashboards de monitoramento e acionamento automático de rotinas inteligentes.

## Descrição do Projeto de Retrofit

Este projeto consiste na modernização (retrofit) de um quadro de chamadas de enfermagem eletrônico, substituindo circuitos eletronicos por um sistema  baseado no microcontrolador ESP32-WROOM, com foco em automação, conectividade e usabilidade.

 Este projeto mantém os botões tipo pera nos leitos para acionamento, mas agora controla arandelas de led via relés, alimentados por fonte de 12V CC. Uma cigarra de aviso é ativada sempre que uma chamada é feita. O sistema é supervisionado por uma interface web responsiva, acessível por Wi-Fi, que exibe o status das chamadas em tempo real, além de dados de temperatura e umidade ambiente por meio de sensores digitais. Através dessa interface, também é possível silenciar temporariamente o buzzer de alerta.

A estrutura modular e a programação flexível do ESP32 possibilitam fácil manutenção e futuras expansões, como notificações remotas, integração com sistemas de automação predial (BMS) e registro de eventos via MQTT. Essa abordagem preserva a infraestrutura existente, reduz custos e eleva o sistema a padrões modernos de eficiência e tecnologia

O projeto completo, incluindo esquemas elétricos, código-fonte e instruções de montagem, está detalhado na documentação disponível no seguinte link:
https://github.com/Epaminondaslage/quadro_de_chamadas/blob/main/Projeto_Quadro_de_Chamadas_ESP32.md

---

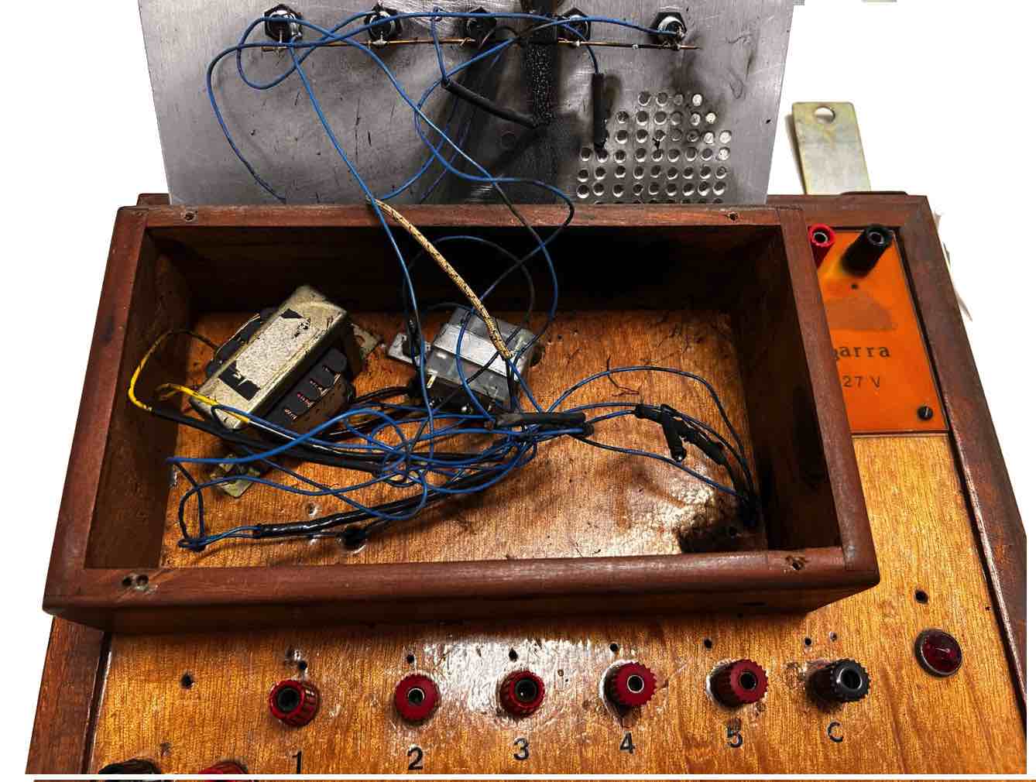
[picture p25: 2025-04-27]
img/quadro_de_chamadas2.jpeg

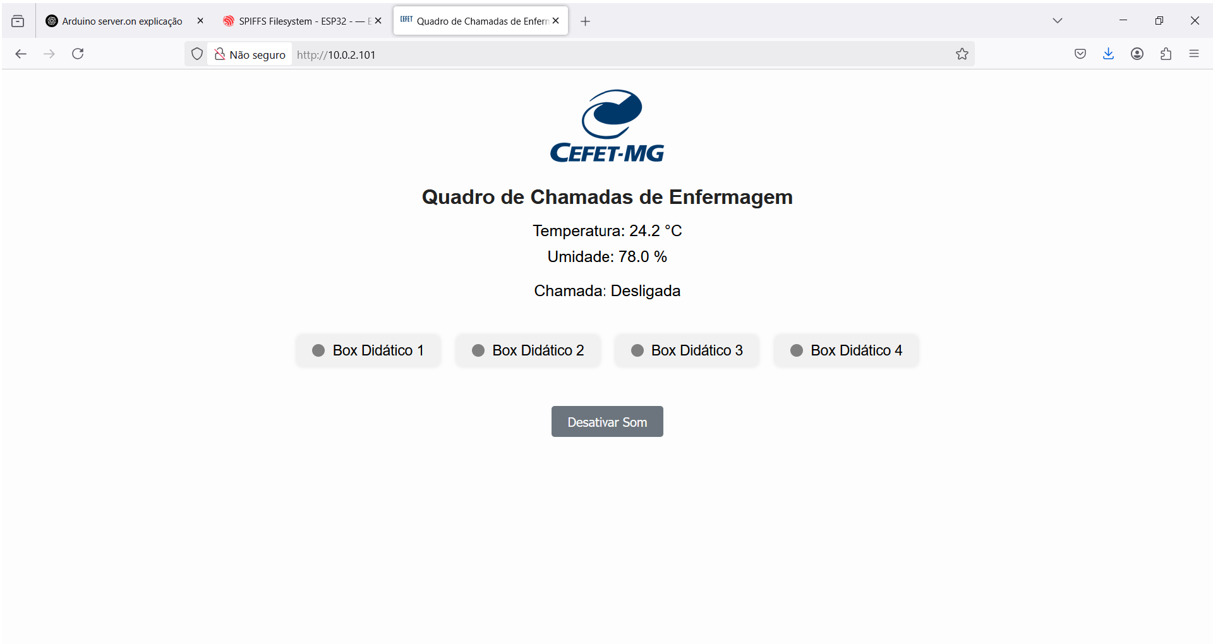
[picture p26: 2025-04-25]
Tela_web.png

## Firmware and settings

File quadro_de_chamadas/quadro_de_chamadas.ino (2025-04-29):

#include <WiFi.h>
#include <WebServer.h>
#include <DHT.h>
#include <FS.h>
#include <SPIFFS.h>

#define SSID "PLT-DIR"
#define PASSWORD "epaminondas"

#define DHTPIN 15
#define DHTTYPE DHT11
DHT dht(DHTPIN, DHTTYPE);

WebServer server(80);

const int entradas[4] = {32, 33, 25, 26};
const int saidas[4] = {4, 5, 18, 19};
const int buzzerPin = 21;
const int botaoMute = 27;

bool buzzerAtivo = false;
unsigned long buzzerDesligadoAte = 0;

// =================================================
// Classe Pisca quando algum box chama a enfermagem
// =================================================
class Pisca {
  private:
    int pino;
    unsigned long intervaloPrincipal;
    unsigned long intervaloPisca;
    unsigned long tempoAnterior;
    unsigned long tempoPisca;
    int estadoPisca;
    bool habilitado;

  public:
    Pisca(int pinoSaida, unsigned long intervalo, unsigned long intervaloEntrePiscas) {
      pino = pinoSaida;
      intervaloPrincipal = intervalo;
      intervaloPisca = intervaloEntrePiscas;
      tempoAnterior = 0;
      tempoPisca = 0;
      estadoPisca = 0;
      habilitado = false;
      pinMode(pino, OUTPUT);
      digitalWrite(pino, LOW);
    }

    void ativar() {
      habilitado = true;
    }

    void desligar() {
      habilitado = false;
      digitalWrite(pino, LOW);
      estadoPisca = 0;
    }

    void atualizar() {
      if (!habilitado) return;

      unsigned long agora = millis();

      if (estadoPisca == 0 && agora - tempoAnterior >= intervaloPrincipal) {
        tempoAnterior = agora;
        estadoPisca = 1;
        tempoPisca = agora;
        digitalWrite(pino, HIGH);
      }

      if (estadoPisca > 0 && agora - tempoPisca >= intervaloPisca) {
        tempoPisca = agora;
        if (estadoPisca % 2 == 1) {
          digitalWrite(pino, LOW);
        } else {
          digitalWrite(pino, HIGH);
        }
        estadoPisca++;

        if (estadoPisca > 6) {
          estadoPisca = 0;
        }
      }
    }
};

// =================================================
// Função para ler arquivos do SPIFFS
// =================================================
bool handleFileRead(String path) {
  if (path.endsWith("/")) path += "index.html";

  String contentType = "text/plain";
  if (path.endsWith(".html")) contentType = "text/html";
  else if (path.endsWith(".css")) contentType = "text/css";
  else if (path.endsWith(".js")) contentType = "application/javascript";
  else if (path.endsWith(".png")) contentType = "image/png";

  if (SPIFFS.exists(path)) {
    File file = SPIFFS.open(path, "r");
    server.streamFile(file, contentType);
    file.close();
    return true;
  }
  return false;
}

// =================================================
// Função para gerar JSON do status
// =================================================
String getJsonAsString(float temperatura, float umidade){
  String json = "{";
  json += "\"temperatura\":" + String(temperatura, 1) + ",";
  json += "\"umidade\":" + String(umidade, 1) + ",";
  json += "\"buzzer\":" + String(buzzerAtivo ? "true" : "false") + ",";
  for (int i = 0; i < 4; i++) {
    json += "\"entrada" + String(i + 1) + "\":" + String(digitalRead(entradas[i]) ? "true" : "false");
    if (i < 3) json += ",";
  }
  json += "}";
  return json;
}

// =================================================
// Parâmetros do pisca
// =================================================
Pisca pisca(2, 1000, 200); // Pino 2, intervalo de 1s, piscadas de 200ms

// =================================================
// Setup
// =================================================
void setup() {
  Serial.begin(115200);
  WiFi.begin(SSID, PASSWORD);
  while (WiFi.status() != WL_CONNECTED) {
    delay(500);
    Serial.print(".");
  }
  Serial.println();
  Serial.println("WiFi conectado");
  Serial.print("IP atribuído: ");
  Serial.println(WiFi.localIP());

  dht.begin();

  if (!SPIFFS.begin(true)) {
    Serial.println("❌ Falha ao montar SPIFFS");
    return;
  }
  Serial.println("✅ SPIFFS montado com sucesso");

  Serial.println("Arquivos SPIFFS disponíveis:");
  File root = SPIFFS.open("/");
  if (!root || !root.isDirectory()) {
    Serial.println("Erro ao abrir diretório raiz SPIFFS.");
  } else {
    File file = root.openNextFile();
    while (file) {
      Serial.print("  ");
      Serial.println(file.name());
      file = root.openNextFile();
    }
  }

  for (int i = 0; i < 4; i++) {
    pinMode(entradas[i], INPUT_PULLDOWN);
    pinMode(saidas[i], OUTPUT);
  }
  pinMode(buzzerPin, OUTPUT);
  pinMode(botaoMute, INPUT_PULLDOWN);

  server.on("/status.json", []() {
    float temperatura = dht.readTemperature();
    float umidade = dht.readHumidity();
    String json = getJsonAsString(temperatura, umidade);
    Serial.println(json);
    server.send(200, "application/json", json);
  });

  server.on("/mute", []() {
    buzzerDesligadoAte = millis() + 60000;
    digitalWrite(buzzerPin, LOW);
    buzzerAtivo = false;
    server.send(200, "text/plain", "Buzzer desativado por 1 minuto");
  });

  server.serveStatic("/", SPIFFS, "/");

  server.onNotFound([]() {
    if (!handleFileRead(server.uri())) {
      server.send(404, "text/plain", "Not found");
    }
  });

  server.begin();
}

// =================================================
// Loop principal
// =================================================
void loop() {
  server.handleClient();
  bool algumaEntradaAtiva = false;

  // Verifica entradas e ativa saídas
  for (int i = 0; i < 4; i++) {
    bool estado = digitalRead(entradas[i]);
    digitalWrite(saidas[i], estado ? LOW : HIGH);
    if (estado) {
      algumaEntradaAtiva = true;
    }
  }

  // Controle do pisca
  if (algumaEntradaAtiva) {
    pisca.ativar();
  } else {
    pisca.desligar();
  }

  pisca.atualizar();

  // Verifica botão de mute
  if (digitalRead(botaoMute) == HIGH) {
    buzzerDesligadoAte = millis() + 60000;
    digitalWrite(buzzerPin, LOW);
    buzzerAtivo = false;
  }

  // Controle do buzzer
  if (millis() > buzzerDesligadoAte) {
    if (algumaEntradaAtiva) {
      tocarAlertaSonoro();
      buzzerAtivo = true;
    } else {
      noTone(buzzerPin);
      buzzerAtivo = false;
    }
  } else {
    digitalWrite(buzzerPin, LOW);
    buzzerAtivo = false;
  }

  // Exibe temperatura e umidade a cada 5s na Serial
  static unsigned long ultimaLeituraSerial = 0;
  if (millis() - ultimaLeituraSerial > 5000) {
    ultimaLeituraSerial = millis();
    float temp = dht.readTemperature();
    float umid = dht.readHumidity();

    if (isnan(temp) || isnan(umid)) {
      Serial.println("❌ Erro ao ler do sensor DHT!");
    } else {
      Serial.print("🌡️ Temp: ");
      Serial.print(temp);
      Serial.print(" °C\t");
      Serial.print("💧 Umidade: ");
      Serial.print(umid);
      Serial.println(" %");
    }
  }
}

// =================================================
// Função do alerta sonoro
// =================================================
void tocarAlertaSonoro() {
  tone(buzzerPin, 1000); delay(150); noTone(buzzerPin); delay(100);
  tone(buzzerPin, 1500); delay(150); noTone(buzzerPin); delay(100);
  tone(buzzerPin, 1200); delay(150); noTone(buzzerPin); delay(300);
}

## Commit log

2025-04-27 Update .$quadro de chamadas.drawio.bkp
2025-04-27 Update 🔧 Retrofit-do-Quadro-de-Chamadas.md
2025-04-29 comit img
    [quadro de chamada.fzz]
2025-04-29 Create quadro de chamadas6.jpg
2025-04-29 Create quadro de chamadas5.jpeg
2025-04-29 Update quadro de chamadas5.jpeg
2025-04-29 Create quadro de chamadas7.jpg
2025-04-29 Update quadro de chamadas7.jpg
2025-04-29 Create quadro de chamadas8.jpg
